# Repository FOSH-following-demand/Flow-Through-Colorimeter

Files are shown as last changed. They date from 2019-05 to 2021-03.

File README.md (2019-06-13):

# Flow-Through colorimeter for activation energy experiments.

The purpose of this project is to design and build a flow-through colorimeter to be used in activation energy experiments.

## Introduction
Leaching is a process for extracting substances from a solid by dissolving them in a liquid. In chemical processing industry, leaching has a variety of commercial applications, from the extraction of copper to the separation of sugar from beetroot.
Heterogeneous reactions are chemical reactions in which the reactants are components of two or more phases, like solid and liquid. Studying the kinetics in heterogeneous reactions is important to optimize industrial processes.
There are two important characteristics of reactions kinetics:
The reaction     rate and the effect of operational conditions, such as temperature,     concentration and stirring speed, among others.
The reaction     mechanism.
The main objective when studying kinetics of a reaction is to determine the activation energy (Ea). To determine the activation energy it is commonly used a small reactor (~1000ml) in which a solid and a certain amount of distilled water are placed. The solution is heated and the operation temperature is set. Then, the leaching substance is added. Afterwards, the concentration of the solution is periodically measured until it reaches the equilibrium. To measure the concentration, a sample is taken and tested. If the reaction develops a color, samples can be tested with a spectrophotometer or a colorimeter. The Lambert-Beer law relates the concentration of a sample to the absorbance of incident light at a given wavelength.

## The problem
In activation energy experiments described above, the size of the reactor is quite small. Thus, taking a sample from the tank to measure the concentration changes the conditions of the experiment (i.e. the volume). Furthermore, if the reaction is relatively fast (~60 minutes) you need to take samples very often (once a minute), making the process too laborious.

## The solution
By means of a flow-through colorimeter with a peristaltic pump you can monitor the experiment continuously and automatically. Moreover, as the solution is flowing continuously from the reactor to the colorimeter and back you avoid the problems associated with changing conditions of the experiment.
Additionally, the flow-through colorimeter will include a temperature probe to measure the temperature of the solution and a PID output to control the heater of the reactor.
Our plan is to build a flow-through colorimeter with a temperature controller to be used in small chemical reactors. We will base our design in the one of [Alex Kutschera](https://www.hackster.io/alexanderkutschera/flow-through-photometer-0226cb).

## Progress

Week 1:
  - Build the repo
  - Search for similar proyects

Week 2:
  - Define the system design
  
Week 3:
  - Buy the materials
  - Sketch of the reactor (3 possible desings).
  
Week 4:
  - Experimets with the false bottom filter
  - Waiting for the components we ordered....

Week 5:

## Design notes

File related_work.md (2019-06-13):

# Related projects
For this project we are using the following projects as inspirations

| Project name  | URL | Active/Not active | Notes - relevance |
| --- | --- | --- | --- |
| DIY spectophotometer | https://github.com/openscienceschool/di-lambda | Active | A modular colorimeter using LEDs as light source and a photodiode as detector |
|Flow-Through Photometer| https://www.hackster.io/alexanderkutschera/flow-through-photometer-0226cb | Active | relatively simple and effective flow through colorimeter |
|  Peristaltic pump controller | https://gitlab.com/pcremades/peripump | Active | A simple persitaltic pump controller |

Moreover, we made a previous research on colorimeters when we developed [our previous prototype](https://gitlab.com/nanocastro/ColorLabFD?nav_source=navbar) based on IO Rodeo Colorimeter

|  **Colorímetro** | **Determinación/Método** | **Fuente de luz** | **Sensor** | **Referencia** |
| :---: | :---: | :---: | :---: | :---: |
|  Open-Source Photometric System | Enzymatic Nitrate Quantification | Green LED<br/>(540 nm) | Taos TSL238 | http://journals.plos.org/plosone/article?id=10.1371/journal.pone.0134989 |
|  Open-Souce Colorimeter | Closed reflux chemical oxygen demand (COD) | Led Naranja (606nm ) | Taos TSL230R | http://www.mdpi.com/1424-8220/13/4/5338/htm |
|  Open-source mobile water quality testing platform | DBO/DQO<br/>Turbidez (ISO 7027) | Led infrarojo (860nm)<br/>Led Naranja (620nm) | Taos TSL235 | http://washdev.iwaponline.com/content/4/3/532 |
|  Colorímetro Educativo<br/>IO Rodeo | Ammonio, Nitratos, fosfatos<br/>http://archive.iorodeo.com/colorimeter/assays | Led RGB<br/>Custom Led | TCS3200D | http://archive.iorodeo.com/colorimeter |
|  Colorímetro<br/>Openplant | Live Cell Density | Led (740 nm ) | Texas Opt101 | https://link.springer.com/article/10.1007%2Fs00284-017-1370-3 |
|  Colorimetros de Hackteria<br/>(educativo/artisticos) | Turbidez, color cerveza, Protein Phosphatase, etc. | Led/Laser | LDR | https://www.hackteria.org/projects/turbidity-meter/ |
|  Open-Source Turbidimeter | Turbidez | Led infrarrojo cercano (860 nm) | Taos TSL230R | https://www.ncbi.nlm.nih.gov/pmc/articles/PMC4029670/ |
|  Hackuarium DIY spectrophotometer | OD, pH, | RGB Led | TSL235 | https://github.com/Hackuarium/simple-spectro |

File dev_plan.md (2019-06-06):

# Development plan

| Week | Activities | Who |
| --- | --- | --- |
| 1 | Research on similar projects | Pablo, Nano |
| 2 | Design of first prototype and compilation of inicial BOM | Pablo, Nano, Mario, Alex|
| 3 | First meeting call with Alex | All |
| 4 | Bluprints of the reactor, buy components, test false bottom | Daina, Pablo, Nano  |
| 5 | Reactor prototype assembly  | Mario, Daiana, Diego, Pablo |
| 6 | Design of the colorimeter and first prototype | Pablo, Nano, Mario |
| 7 | | |
| 8 | | |

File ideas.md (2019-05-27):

## This is the place to put things in really raw state

### Possible sensors  
https://learn.sparkfun.com/tutorials/spectral-triad-as7265x-hookup-guide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  
 https://ams.com/documents/20143/36005/TCS3471_DS000109_3-00.pdf

### Peristaltic pumps
- We should define the maximum pump flow rate required...
- Hose material?
https://articulo.mercadolibre.com.ar/MLA-768684396-bomba-peristaltica-12v-arduinoetc-rosario-_JM?quantity=1  
https://de.aliexpress.com/item/Gikfun-12V-DC-Dosing-Pump-Peristaltic-Dosing-Head-with-Connector-For-Arduino-Aquarium-Lab-Analytic-Diy/32725118884.html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  

### Temperature sensor
- Rango y precisión?
http://tienda.ityt.com.ar/mercadolibre/238-modulo-max6675-termocupla-k-spi-sensor-temperatura-itytarg.html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

### Temperature control output type?
how are going to do this? maybe we can take a look here?  https://www.hackster.io/open-bioeconomy-lab/microbial-bioreactor-d7f61b this is another project with Alex @vectorious participation! 

### Software
- Type of data to be collected, format, time interval, live analysis?

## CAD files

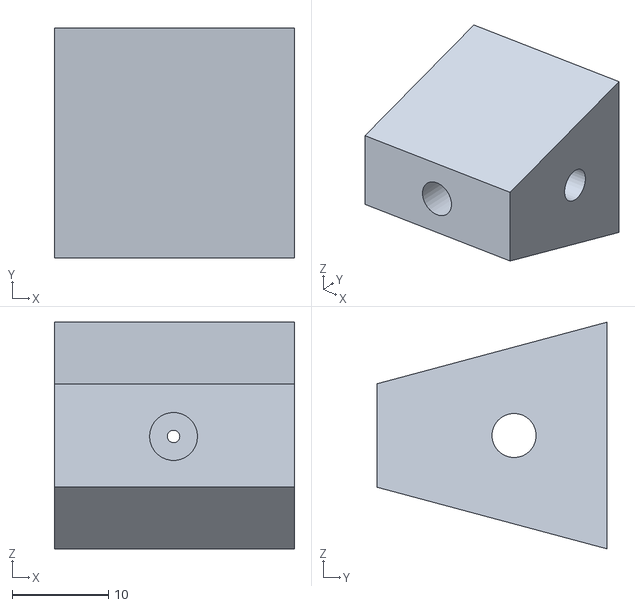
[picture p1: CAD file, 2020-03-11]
hardware/mechanics/flow_chamber_trapezoidal.stl
25.0 x 24.0 x 23.6

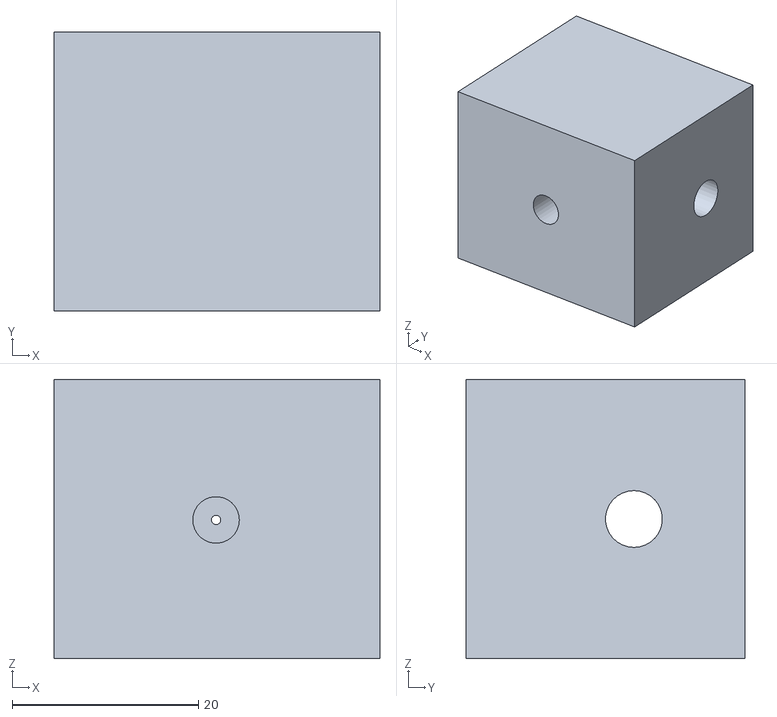
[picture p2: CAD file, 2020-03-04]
hardware/mechanics/flow_chamber.stl
35.0 x 30.0 x 30.0

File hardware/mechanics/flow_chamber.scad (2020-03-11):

// ******Flow Through colorimeter Nano Castro, Pablo Cremades****//

$fn=30;
// Parametros del cubo de medición
cube_h=24; 
cube_w=24;
cube_l=25;

// Parámetros TCS34725
tcspcb_w=0.8*25.4;
tcspcb_l=0.8*25.4;
tcspcb_depth=3;
tcspcb_led_h=1.4;
sensorloc_w=0.39;//ubicación del sensor en ancho pcb
sensorloc_l=0.41;//ubicación del sensor en alto pcb
sensor_w=2;
sensor_l=2.4;

// Parámetros del OPT101
//sensor_w=6.12;
//sensor_l=9.34;
//sensor_depth=1.45;
// Parametros de photodiodo
//photo_w=2.2;

// Parametros del tubo
tube_diam=4.5+0.1;//corregido 0.1
// Parametros del LED
led_diam=5;
led_l=7;
// Parametro haz de luz
light_diam=1+0.3;//corregido 0.3

difference(){
cube([cube_l,cube_w,cube_h],center=true);

/// Para OPT101
//translate([0,cube_w/2-sensor_depth/2,0])
//cube([sensor_l,sensor_depth,sensor_w],center=true);//abertura para sensor
//translate([0,cube_w/2-tube_diam/2,0])
//cube([photo_w,tube_diam,photo_w],center=true);

translate([-tcspcb_w/2,cube_w/2-tcspcb_depth,-tcspcb_l/2])
cube([tcspcb_w,tcspcb_depth,tcspcb_l]);

rotate([0,90,0])
translate([0,tube_diam/2,-0.1])
#cylinder(r=tube_diam/2,h=3*cube_w,center=true);//abertura para paso del tubo de fluido
     
translate([-0.1,-cube_w/2+led_l/2,-0.1])
rotate([90,0,0])
    cylinder(r=led_diam/2,h=led_l,center=true);//abertura para led
rotate([-90,0,0])
cylinder(d=sensor_l,h=cube_w/2);
translate([-0.1,0,-0.1])
rotate([90,0,0]) 
#cylinder(r=light_diam/2,h=1.5*cube_w,center=true);

//arreglo para imprimir....
translate([0,cube_w/5,0])
rotate([30,0,0])
translate([-cube_w/2-2,-cube_w,-cube_l/2-2])
rotate([0,90,0])
cylinder(cube_l+2,cube_l,cube_l,$fn=4);

mirror([0,0,1])
translate([0,cube_w/5,0])
rotate([30,0,0])
translate([-cube_w/2-2,-cube_w,-cube_l/2-2])
rotate([0,90,0])
cylinder(cube_l+2,cube_l,cube_l,$fn=4);

}

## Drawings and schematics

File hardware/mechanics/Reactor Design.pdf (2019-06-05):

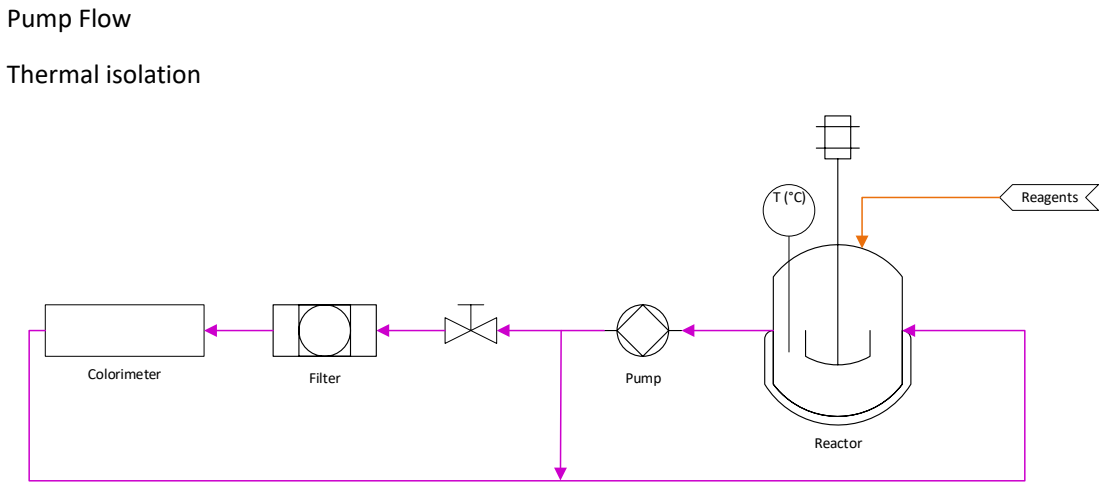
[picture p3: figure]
Pump Flow; Thermal isolation; Reactor; Pump; Filter Colorimeter; Reagents

1

Flowsheet A

The circulating fluid passes through the peristaltic pump, stopcock, filter and colorimeter, returning then to the reactor.

Keypoints to determine:

Kind of filter

Flowsheet A

Flowsheet B

This system contains the filter inside the reactor, so the fluid filters inside it, passing then through the peristaltic pump to the colorimeter.

Keypoints to determine:

Kind of filter and structure

Pump flow

Thermal isolation

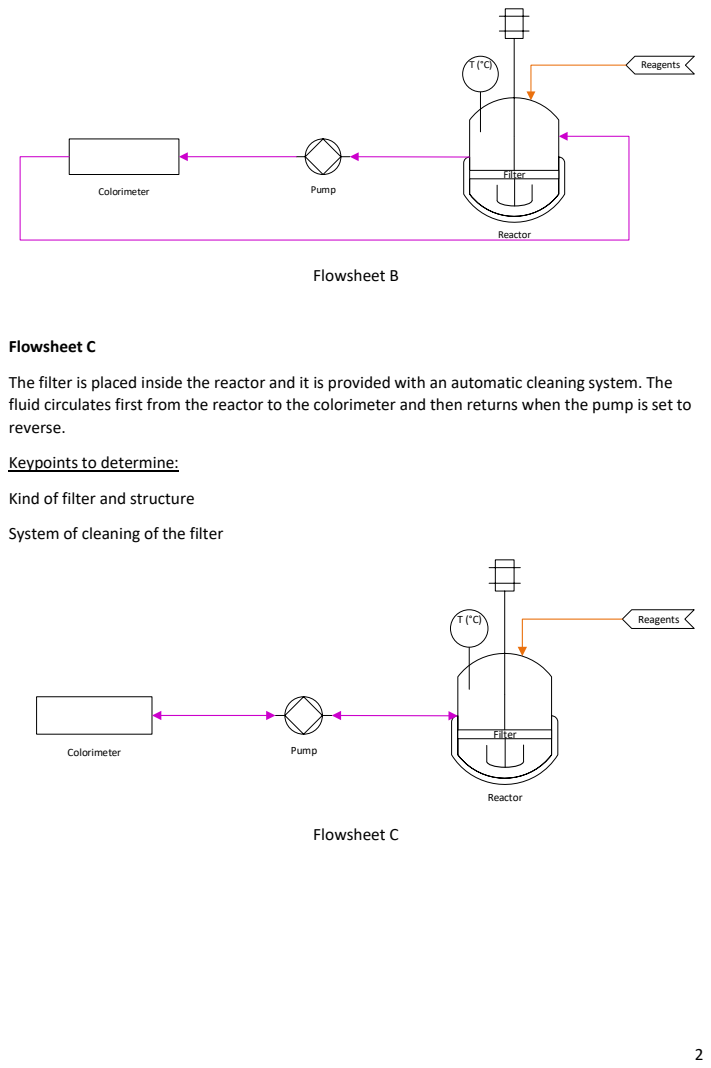
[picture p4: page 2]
Reagents; Reactor; Filter; Colorimeter; Pump; Flowsheet B; Flowsheet C

The filter is placed inside the reactor and it is provided with an automatic cleaning system. The
fluid circulates first from the reactor to the colorimeter and then returns when the pump is set to
reverse.

Keypoints to determine:

Kind of filter and structure

System of cleaning of the filter

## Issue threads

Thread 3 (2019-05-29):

Reactor design requirements and associated issues

nanocastro, 2019-05-29:
@pcremades and  Mario were talking about the design of the reactor and the requirements for the flow-through colorimeter
@vektorious take a look and ask us if you don't get something in the drawing

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

### Design requirements and associated issues:

- The liquid inside the reactor must be heated to temperatures below 100 °C.
The liquid in the reactor is corrosive so the it must be heated from outside (heater plate + stirrer) and the temperature thermocouple (J type) must be placed inside a glass tube filled with grease for better conductivity
- The liquid to be sampled contains suspended solids so must be filtered before entering the colorimeter (F in the drawing)
This means that the measure can not be continuous but pulsed in order to avoid the filter clogging.
It also means that a by-pass valve is needed in order to change the filter in case is needed
- The sample must be measured at almost the same temperature as the liquid in the reactor (+-2°C)
The sampling hose should be isolated and close enough to the reactor
After each measuremente the liquid in the sampling hose must be evacuated?

pcremades, 2019-05-31:
We are thinking about including a false bottom inside the reactor so that at least coarse particles would never enter the tubing at all. That would extend the life of the secondary filter next to the photometer. We would then need to change that filter every 6 to 10 measurements (i.e. one hour or so).
By reverting the pump, we could send the solution back to the reactor and there would be no need to have a bypass.
Daiana, can you upload a sketch of the reactor with the false bottom?

daiananavarrete, 2019-05-31:
Hi! Ok, We´ll do it and upload it when it is ready.

vektorious, 2019-06-03:
If you make a new sketch anyway you might want to do it digitally. You probably already know [Inkscape](https://inkscape.org/de/) which is an OS vector drawing software. I used it for [my sketches](https://github.com/vektorious/lightM#how-can-you-contribute) too. You can also import hand drawings and convert them to vector graphics.

daiananavarrete, 2019-06-05:
Hi! Thanks for the suggestions about Inkscape. We uploaded the flowsheet of the design reactor to discuss about the thematic.

https://github.com/FOSH-following-demand/Flow-Through-Colorimeter/blob/master/hardware/mechanics/Reactor%20Design.pdf

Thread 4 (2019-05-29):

Review of first prototype parts for BOM

nanocastro, 2019-05-29:
We are reviewing some possible parts for the first prototype
## Possible light sensors
https://learn.sparkfun.com/tutorials/spectral-triad-as7265x-hookup-guide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
https://ams.com/documents/20143/36005/TCS3471_DS000109_3-00.pdf
http://tienda.ityt.com.ar/mercadolibre/7228-sensor-de-color-rgb-tcs34725-5v-i2c-itytarg.html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

## Peristaltic pumps
We should define the maximum pump flow rate required...
Hose material? https://articulo.mercadolibre.com.ar/MLA-768684396-bomba-peristaltica-12v-arduinoetc-rosario-_JM?quantity=1
https://de.aliexpress.com/item/Gikfun-12V-DC-Dosing-Pump-Peristaltic-Dosing-Head-with-Connector-For-Arduino-Aquarium-Lab-Analytic-Diy/32725118884.html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
## Temperature sensor
Rango y precisión? http://tienda.ityt.com.ar/mercadolibre/238-modulo-max6675-termocupla-k-spi-sensor-temperatura-itytarg.html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
http://tienda.ityt.com.ar/mercadolibre/723-sensor-sonda-temperatura-ds18b20-cable-1m-arduino-itytarg.html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

vektorious, 2019-06-03:
I already gave some feedback during the call but I wanted to collect it here, too.

### Sensors
You might want to do some research which one would be better for your application. You can still use the opt101 + LED with specific wavelength if you only have to measure at one waveleght but then it is no real colorimeter

### Peristaltic pumps & tubing
Most of the pumps have only a very small diameter tubing, have a look at that! For the Pasteur pipette photometer I used silicone tubing with an inner diameter of 5 mm and had an adapter to connect it with the peristaltic pump

### Temperature sensor
I like the ds18b20 quite a lot. Super easy to use.

nanocastro, 2019-06-05:
We started with the purchase of things we will need
[comprasBFOSH.pdf](https://github.com/FOSH-following-demand/Flow-Through-Colorimeter/files/3258358/comprasBFOSH.pdf)

vektorious, 2019-06-06:
Looks good to me!
Be careful with those RGB LEDs because they don't have a linear emission in the VIS-spectrum because they "just mix" the light from the single LEDs with a narrow bandwidth. There is no better solution for this (apart from using a light bulb with a broad light spectrum and a prism which adds a new level of complexity) but check the spec sheets for the LED and maybe develop a calibration scheme.

pcremades, 2019-06-07:
We are aware of the spectral emission of RGB LEDs. We chose that one because we need to measure at 540nm (green led) and the RGB LED board simplifies the assembly and is widely available in the local market. There might be also some other reactions we could measure with the red led.

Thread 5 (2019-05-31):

Magnetic stirrer

pcremades, 2019-05-31:
We could use a commercial magnetic stirrer and hack the electronic controller.
Another option would be to use an MK2 heated bed (the one that 3D printers use) and design a magnetic stirrer. The benefit would be that this solution is cheaper and parts are more widely available.

amchagas, 2019-05-31:
Cool, I would also suggest to have a chat with the team building an pcr machine. they are having to deal with temperature control too! @MaxZimmer maybe have a look here?

pcremades, 2019-05-31:
@amchagas , couldn't find any discussion about temperature control in the [repo](https://github.com/FOSH-following-demand/PCR_thermal_cycler)...

amchagas, 2019-05-31:
Maybe they didn't upload it yet, but the discussions have been taking place. you can also ping them on their slack channel.
On a related note, these might be interesting
https://hackaday.com/2018/04/14/pid-control-with-arduino/

http://brettbeauregard.com/blog/2011/04/improving-the-beginners-pid-introduction/

pcremades, 2019-05-31:
Thanks André. I used the code from Brett to control an inverted pendulum, so I have experience with that one. Anyway, if we decide to go for a MK2 heated bed, then we can use the PID control in Marlin firmware. They already figured out the PID coefficients for that bed.

pcremades, 2019-06-03:
I've been reading and apparently, the MK2 heated bed can reach 110°C in 30 min with a 24V power supply. Would this be enough to heat the reactor?

vektorious, 2019-06-03:
Depends on the temperature you need to reach. I guess it will be impossible to heat it above 100 and it will take a lot longer than the 30 min to heat up the liquid just to 50 degrees. But this also depends on the volume of the reactor.

[We used a water bath to heat our microbe reactor](https://www.hackster.io/open-bioeconomy-lab/microbial-bioreactor-d7f61b) which is much faster and makes uniform heating easier. We also thought about wrapping the reactor with a heating pad.

guadapinna, 2019-06-04:
The idea is to work in a water bath, calculation that reaches about 80 degrees would be fine.

vektorious, 2019-06-04:
If you want to go to higher degrees (above 100), you can use glycerol (which is more expensive).

pcremades, 2019-06-06:
Ok, now I think we are going in another direction. As we will be using a water bath, it would be easier to use an immersion electric heater and forget about the heated bed. It will be cheaper as well.

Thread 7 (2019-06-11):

Type of filter

dsdrajlin, 2019-06-11:
We have to decide on the kind of filter that we will use. We had thought that the filter could be inside the reactor, so we need to make sure it has:

- Mechanical resistance

- Chemical resistance

- Ability to filter different particle sizes

In order to evaluate this, we conducted experiments with two type of filters: a commercial blue ribbon 5893 Blauband filter (filter paper) and a filter made out of a synthetic fabric.
In both experiments, a wire was used to form a ring and the filter was attached. Then the filters were submerged in a saturated tartaric acid solution (a weak acid) at 75 °C (348 K), with stirring for 30 min. The reactor was set inside a water bath to keep temperature constant.

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
Figure 1. Filter paper experiment.

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
Figure 2. Synthetic fabric experiment.

**Results**

Regarding the filter paper, we arrived to the following conclusions:

- It has enough mechanical resistance. There were some minor breakages in the edges but those were because of the poor attachment, which we will have to improve.

- It was resistant to the chemical attack by a weak acid.

- According to specifications, it should be able to retain even smaller particles.

- It is hard to manipulate when it is wet.

- If too close to the bottom, it limits the speed of the stirring because the magnetic piece collides with it.

Regarding the synthetic fabric filter, we arrived to the following conclusions:

- It has good mechanical and chemical resistance (better than the filter paper).

- It is cheap and widely available.

- It might not filter the smallest particles.

- It is easier to manipulate when it is wet.

- The same limitations regarding the speed of the stirring are present but it is easier to adjust the height of the filter.

On the whole, both filters are good enough regarding the purposes of having mechanical and chemical resistance to weak acids. Next, we should proceed carrying out experiments with the solid.

vektorious, 2019-06-11:
Great work! 👍 🎉

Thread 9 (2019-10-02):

Optical sensor

pcremades, 2019-10-02:
Hi Alex,
Just a simple question. Why did you make the hole facing the photodiode and the one facing the LED so small? How did you choose the diameter?

regards,

vektorious, 2019-10-06:
Hey Pablo,
the hole is determining the aperture. The sensor is very sensitive and by changing the hole diameter one can regulate the light load on the sensor. The size for the hole is empirical and I usually have to widen it a bit with a hot needle to get the best measuring range. That's something you have to test:

1. Assemble the photometer, determine the max measure value by shining light directly on the sensor.
2. Set the sensitivity of the sensor (poti at the back) so the value of a measurement with a water-filled test tube is a bit (50 units) below the maximum value.
3. If you never reach max value with a water-filled test-tube (and setting the poti at the back of the sensor pcb) you have to increase the hole size.

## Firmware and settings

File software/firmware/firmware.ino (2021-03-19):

#include <Wire.h>
#include "Adafruit_TCS34725.h"
#include <max6675.h>


/*************************************************************
Notes:
- Timer 2 is used as clock. This means that PWM on pins 3 and 11
cannot be used.
*************************************************************/

/* Sensor de color TCS34725 */
/* Connect SCL    to analog 5
   Connect SDA    to analog 4
   Connect VDD    to 3.3V DC
   Connect GROUND to common ground */
   
/* Termocupla MAX6675 */
/* VCC  to  5V DC
   GND  to  GND
   SCK  to  pin 6
   CS   to  pin 5
   SO   to  pin 4 */
#define thermoDO  4
#define thermoCS  5
#define thermoCLK 6

/* Control de Bomba */
#define  pwmBomba  9   //--------------------> Need a different pin to control pump direction.

/* Initialize color sensor */
Adafruit_TCS34725 tcs = Adafruit_TCS34725(TCS34725_INTEGRATIONTIME_101MS, TCS34725_GAIN_4X);
uint16_t r, g, b, c;
boolean doMeasure = false;

/* Initialize thermocouple */
MAX6675 thermocouple(thermoCLK, thermoCS, thermoDO);

String inputString;
boolean stringComplete = false;

//Time between measurements
#define  TIMERseconds  5
int count=0;
boolean flag=false;


void setup(){
 Serial.begin(9600);
 inputString.reserve(50);
 
 if (tcs.begin()) {
    Serial.println("Found sensor");
  } else {
    Serial.println("No TCS34725 found ... check your connections");
    while (1);
  }
  
 setTimer();
}


void loop(){
   
  //Should we do a measurement?
   if( flag & doMeasure){
     flag = false;
     measure();
   }
   
   //New command to parse?
   if( stringComplete ){
      Serial.println(inputString);
      parseCommand();
      inputString = "";
      stringComplete = false;
   }
   
}

//Set Timer 2 to work as clock to set interval between measurements.
void setTimer(){
  TCCR2A &= 0x0;  //CTC mode
  TCCR2A |= 0x2;
  TCCR2B &= !(0x0F); //Clear prescaler settings
  TCCR2B |= 0x7; //Fcpu/1024 -> 16Mhz/1024 = 15625
  OCR2A = 125;  //Count 125 pulses. -> 15625/125 = 125
  TIMSK2 |= (1 << OCIE2A); // Enable CTC interrupt 
}

//This routine is executed once every 1/125 seconds (see calculations above).
//Then, every 124 calls to this function we get 1 second.
ISR(TIMER2_COMPA_vect){
  count++;
  if(count == 124*TIMERseconds){
    count = 0;
    flag = true;
  }
}

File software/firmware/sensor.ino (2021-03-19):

void calibrate(){
 doMeasure = false;
 c = 0;
 int intense = 50;
 
 while( c < 65500 & intense < 255){ 
  intense++;
  analogWrite( 9, intense );
  delay( 2 );
  tcs.getRawData(&r, &g, &b, &c);
  Serial.print(c);; Serial.print("  "); Serial.println(intense);
 }
 Serial.print( "Calibrado: " );
 Serial.println( intense );
}

void measure(){
  long rCum=0, gCum=0, bCum=0, cCum=0;
  for( int i = 0; i < 5; i++ ){
    tcs.getRawData(&r, &g, &b, &c);
    rCum += r; gCum += g; bCum += b, cCum += c;
  }
  rCum /= 5; gCum /= 5; bCum /= 5; cCum /= 5;
  Serial.print("R: "); Serial.print(rCum, DEC); Serial.print(" ");
  Serial.print("G: "); Serial.print(gCum, DEC); Serial.print(" ");
  Serial.print("B: "); Serial.print(bCum, DEC); Serial.print(" ");
  Serial.print("C: "); Serial.print(cCum, DEC); Serial.print(" ");
  Serial.println(" ");
}

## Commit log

2019-05-21 Arrancamos con el repositorio. Agrego primeras actividades
2019-06-05 Add files via upload
    Flowsheet of the reactor design to discuss alternatives.
2019-06-13 Update contributing.md
    Agrego formas de contribuir
2019-06-13 Update related_work.md
    Link to the peristaltic pump controller
2020-03-04 flow chamber
    [flow_chamber.scad, flow_chamber.stl]
2020-03-04 cambio de carpeta
    [flow_chamber.scad, flow_chamber.stl]
2020-03-04 Subo primera versión de firmware, librerias necesarias y un código para probar el sensor de color
2020-03-11 partes de fritzing y cambio de flow_chamber
    [Schematic.fzz, Thermocouple.fzz, flow_chamber.scad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]
2020-03-12 Subo datos del sensor de color tomados en la prueba con colorante. Actualizo firmware: usa Timer2 para programar intervalo entre mediciones.
    Falta programar el tema de calibración y mediciones propiamente dichas.
